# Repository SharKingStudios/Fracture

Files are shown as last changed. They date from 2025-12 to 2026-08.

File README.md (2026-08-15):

# Fracture - The Infinitely Chainable MIDI Keyboard

### A modular, glowing wall of keys with its own brain, synth, and buzzer per board.

---

## Renders  
*Visuals because everyone loves eye candy.*

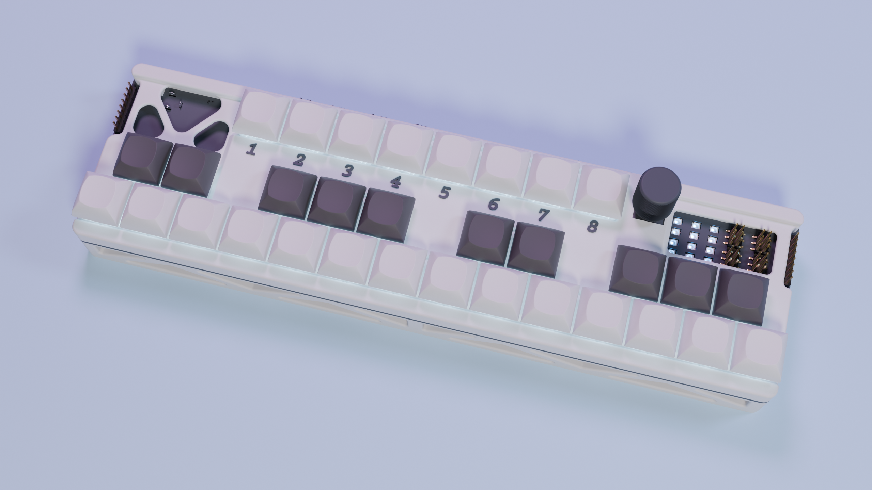
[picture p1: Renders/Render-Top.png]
Front Render

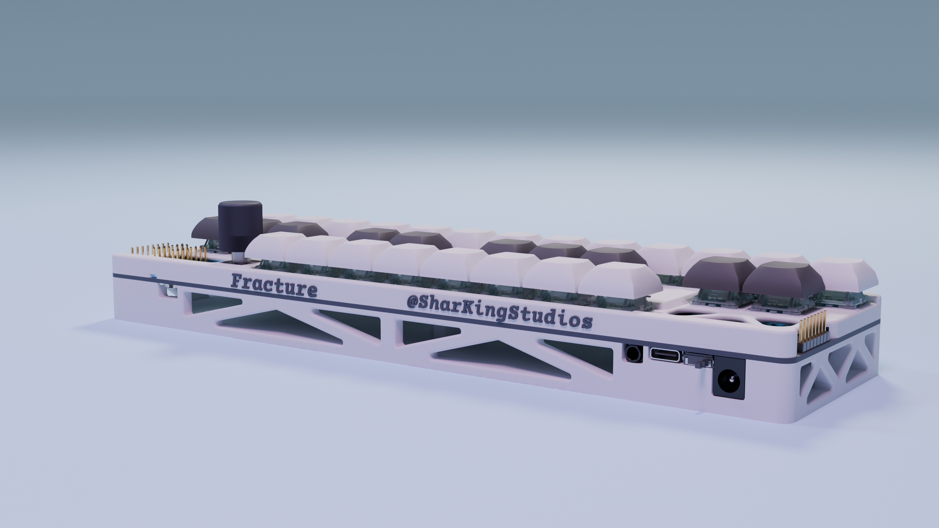
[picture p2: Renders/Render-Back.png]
Angled Render

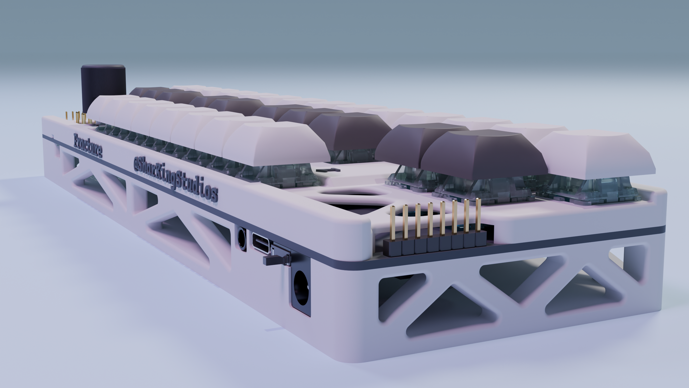
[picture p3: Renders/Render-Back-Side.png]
Angled Render

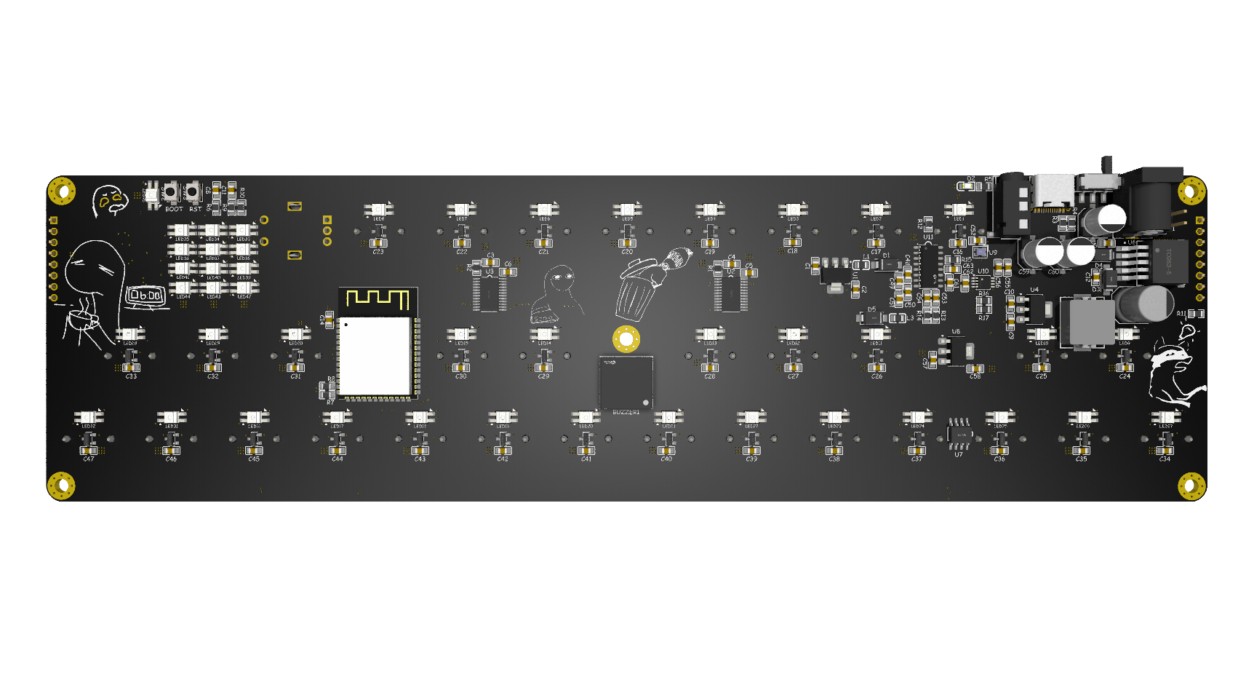
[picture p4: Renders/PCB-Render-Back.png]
Back PCB Render

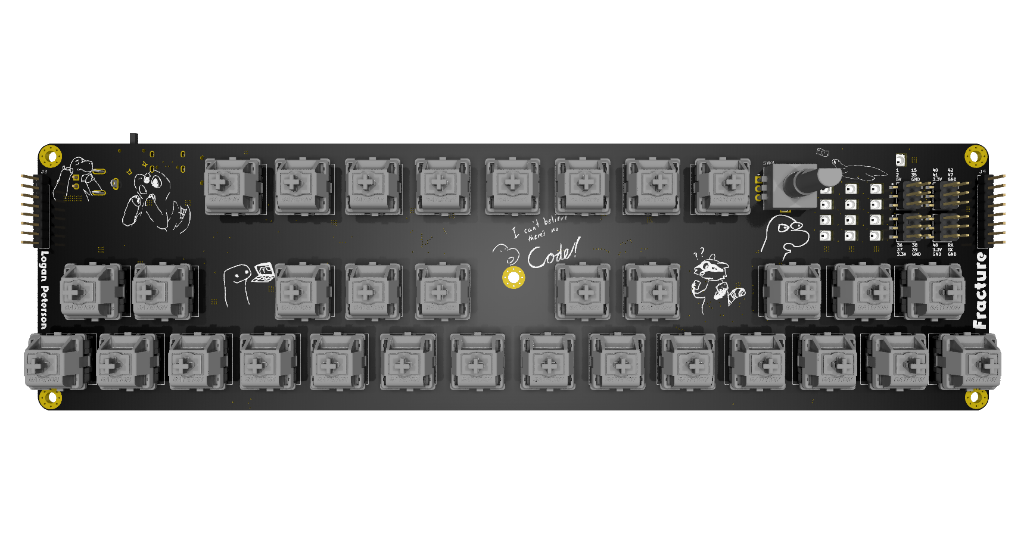
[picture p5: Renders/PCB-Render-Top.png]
Top PCB Render

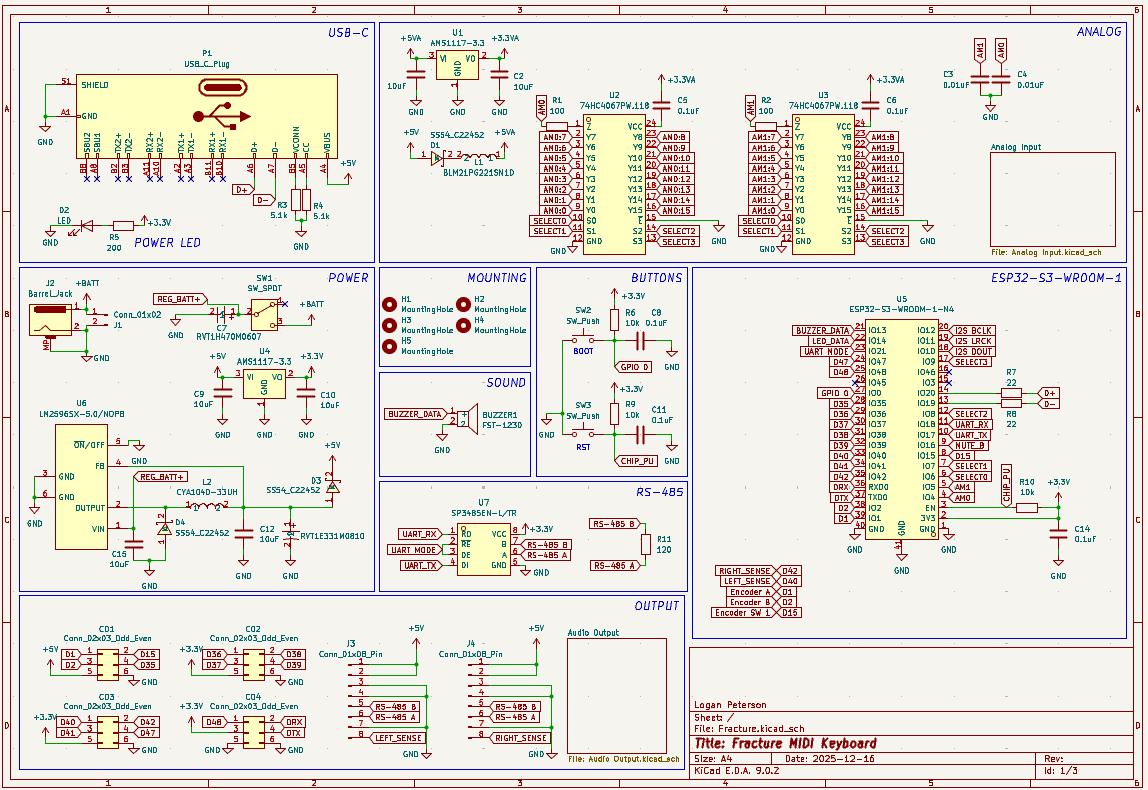
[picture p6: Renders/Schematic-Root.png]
Schematic Overview

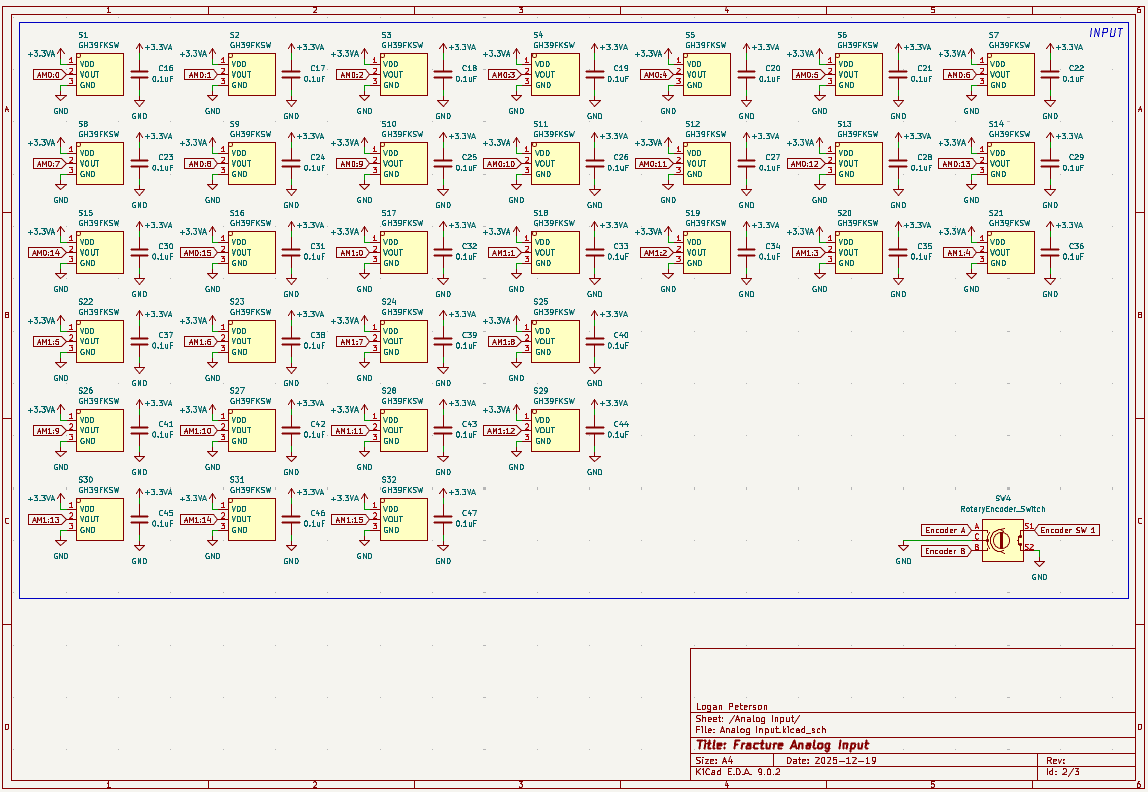
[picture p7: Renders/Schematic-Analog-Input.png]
Schematic Overview

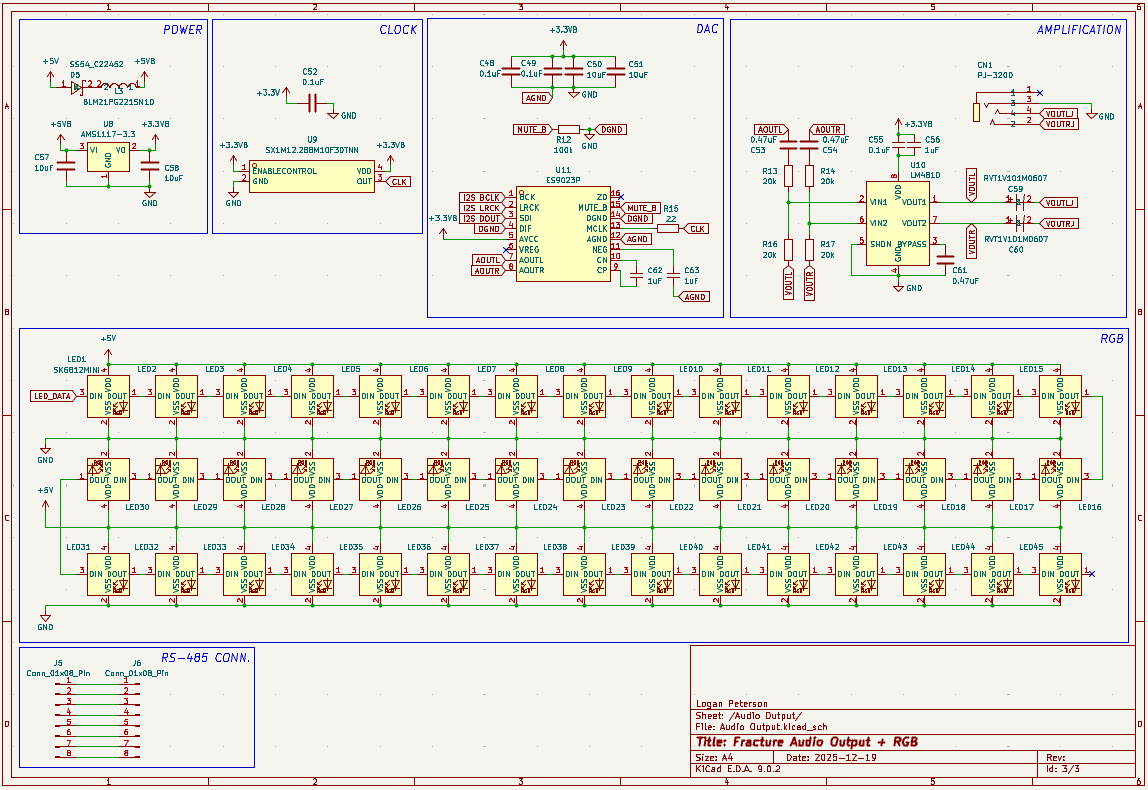
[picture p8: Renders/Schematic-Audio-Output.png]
Schematic Overview

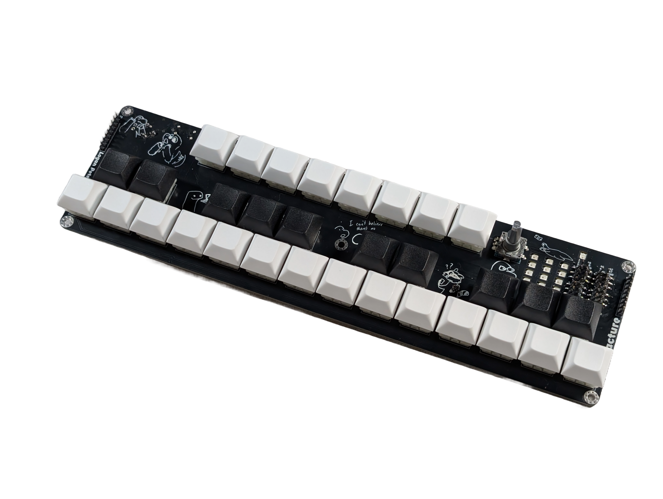
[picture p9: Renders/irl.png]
Irl Picture


---

## What is this?

It's an infinitely expandable MIDI keyboard system built around an ESP32-S3, designed so each board is a fully-featured synth module. When you connect a bunch together, they behave like one giant, continuous instrument.
Each board gives you **2 octaves** of hall-effect keys (24 main keys), plus 8 “function” keys for extra tricks. It also has **onboard I2S audio output**, a buzzer synth per board, and 45 addressable RGB LEDs for underglow + status.
Boards talk to each other over **RS-485 chaining** so note events get shared, and it also does **USB MIDI**, meaning any board plugged into your computer speaks for the whole keyboard.

One board is fun.  
Four boards gives you a full velocity sensing piano.

---

## Features

### Infinitely Chainable Boards

Each board is its own little 2-octave chunk: **24 main keys** and **8 extra keys** for function/mode stuff. The boards discover each other physically using an **RS-485 bus** (SP3485) and **left/right neighbor sense pins**, so you can keep chaining them together.

---

### Hall-Effect Velocity Sensing

No mushy rubber domes here. Keys are read using dual **74HC4067 analog multiplexers**, and velocity is computed using the time between “start of motion” and “fully pressed”.

It’s all done in firmware - no external velocity hardware, just some math and a lot of analog readings.

---

### Onboard Polyphonic Synth (I2S DAC)

Each board is a tiny synth. It uses an **ES9023P I2S DAC** driven at **44.1 kHz, stereo**, and supports up to *8 simultaneous voices*.

You don’t *need* a computer to hear anything, the keyboard can sing on its own.

---

### Polyphonic Buzzer Per Board

Because one audio path wasn’t enough. Each board also has a **timer-driven buzzer synth** that runs at a **20 kHz sample rate**. It’s used for a startup jingle, any feedback sounds, and mild harassment of anyone nearby.

---

### RGB Overlay (Key Underglow + Debug UI)

Each board has **45 WS2812 LEDs** and they’re not just there to look pretty (but they do). Every note triggers a *“splash in the pond”* ripple, and the ripple spreads based on *MIDI note distances*, not physical LED position. Since note events are shared over RS-485, the ripple effect works *across all boards*.

Basically: the keyboard tells you how it feels in RGB.

---

### USB MIDI for the Entire Chain

Any board plugged into USB exposes MIDI for **all** boards. So you can plug in literally any board in the chain, open your DAW / synth, and play the entire keyboard from that one cable.

---

### Rotary Encoder

Because knobs are scientifically proven to make things better.

Long Top Render

---

## BOM

All the silicon, magnetics, and glowsticks live **[here](/BOM.csv)**.

---

### CAD

The CAD is open source **[here](https://cad.onshape.com/documents/bea10ccfe312cfdc51de28f9/w/cdd1b06aedba101817164f81/e/67c5d527eacfd380be4e1fa2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)**.

---

## Why?

Because regular MIDI controllers are boring. Off-the-shelf keyboards don’t re-map themselves and you usually cant chain them together.

Fracture exists to be modular, mildly smart, and just slightly over-engineered.

I honestly thought this would be an easier project, but feature creep got the best of me...

---

## Usage

After you have your board, follow [this guide](/Firmware/Fracture_Keyboard/SONG_MODE.md) for flashing settings and flash [Fracture_Keyboard.ino](/Firmware/Fracture_Keyboard/Fracture_Keyboard.ino) onto your board.

---

## Contribute

Ideas, improvements, and constructive roasting welcome.

- Open an **issue**
- Submit a **PR**
- Or suggest cursed new expansion ideas

---

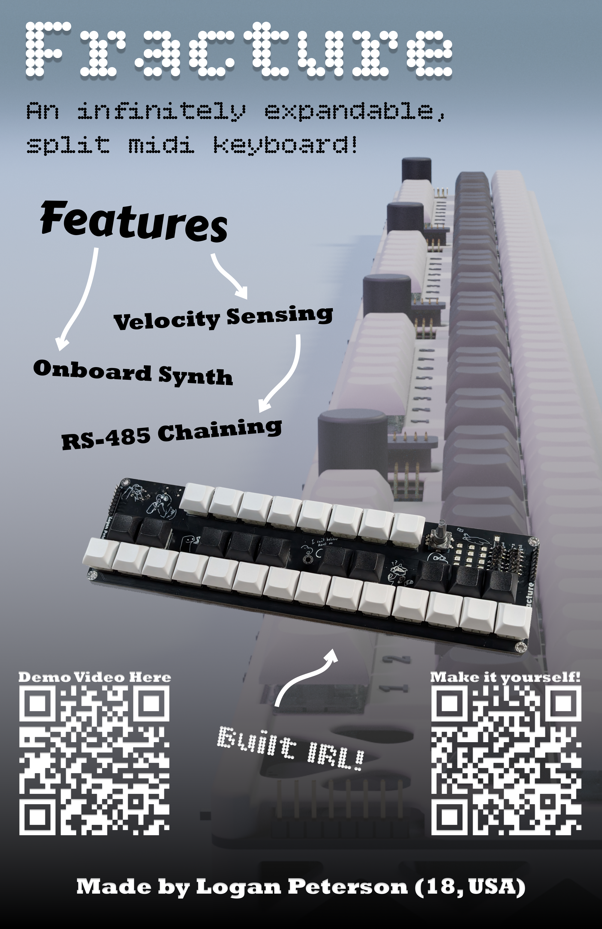
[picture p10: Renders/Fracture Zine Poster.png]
Fracture Poster


## Disclaimer

This project is open-source and powered by *vibes and a sprinkle of C++*.

If you:
- Somehow mess up the RS-485 bus 
- Drive speakers directly off something that shouldn’t  
- Misconfigure power and let the smoke out  

That’s on you.

Be careful, be smart, and enjoy building a keyboard that expands with your musical ability.

Long Side Render

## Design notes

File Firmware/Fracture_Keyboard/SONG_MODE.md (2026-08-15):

# Song Learning Mode

## Arduino settings

The song drive requires a partition scheme containing a partition named `ffat` and TinyUSB/USB-OTG mode.

- Generic ESP32-S3 with 4 MB flash: use `Partition Scheme > No OTA (2MB APP/2MB FATFS)` and `USB Mode > USB-OTG (TinyUSB)`.
- Keep `USB CDC On Boot`, `USB Firmware MSC On Boot`, and `USB DFU On Boot` disabled. Fracture must configure USB itself before `USB.begin()` so normal MIDI and loader MSC do not race each other.
- The stock Arduino Nano ESP32 profile enables USB services before `setup()` and does not expose controls to disable all of them. It is therefore not supported by this composite MIDI/song-loader firmware; use an ESP32-S3 profile that exposes the settings above.
- Do not select a SPIFFS-only partition. When the real `ffat` storage cannot open, loader mode falls back to a small diagnostic USB drive named `SONG LOADER` with a `README.TXT`.

The first boot formats a blank FAT partition. Later mount failures are not auto-formatted, so an unsafe disconnect cannot silently erase stored songs.

## Controls

Normal mode:

- `S6`: enter song select.
- `S7`: refresh/reorder the connected boards.
- Encoder press: toggle the shared buzzer immediately.

Song modes:

- Encoder rotation: move through songs or the available hand choices.
- Encoder press: select/confirm.
- `S1`: escape/back. From the USB loader it safely leaves loader mode after eject/copying is complete.
- `S2` / `S3`: shared octave down/up by one octave. `S4`: reset to the base octave. `S5`: reveal the current title. Audio toggles from normal mode only.
- `S6`: intentionally does nothing while a song mode is active. It cannot delete songs.
- `S7` / `S8`: previous/next browser item or hand choice. If `LOAD SONG` is selected, `S8` enters the loader.

The first browser item is always `LOAD SONG`. Every other entry is collected from the FAT storage on every connected board, so a song stored on one board can be selected from any board.

## Loading files

1. Connect a USB **data** cable directly from the computer to the board on which you want to store the file. The inter-board link does not expose a computer drive.
2. Press `S6` on that board, leave `LOAD SONG` selected, and press the encoder or `S8`. The selected board turns green and the other boards remain orange, so the USB target is unambiguous.
3. The selected board restarts into loader mode and mounts its **actual song library** as the `Fracture Songs` drive. It remains a MIDI device while the drive is present; normal boots expose MIDI only. The restart is required so USB can enumerate the storage interface safely.
4. Use the computer's file explorer to add, rename, or delete Standard MIDI files (`.mid` or `.midi`, format 0 or 1). The current songs are visible immediately; there is no separate staging area.
5. Eject the drive in the operating system. If eject is unavailable, wait for copying to finish and press `S1`.

The loader gives the computer exclusive access to that board's song library. Always eject before pressing `S1` or disconnecting USB; after exit, the firmware restarts, rescans the files, sends a green update wave from the leftmost key to the rightmost key, and rebuilds the distributed song list.

Outside song-menu navigation, encoder rotation changes the shared octave in one-octave steps. In the song browser and hand selector, it moves the menu selection instead.

The loader presents the board's existing FFat song volume directly, using its native wear-leveling geometry. Do not open or change files on both the board and computer at once; loader mode makes the board's local filesystem inactive until it exits.

## Learning behavior

Notes sharing the same MIDI tick are treated as a chord. The guide remains on that chord until every required note has been pressed; wrong notes do not advance it.

- Left hand: green.
- Right hand: red.
- Unknown hand: red.

Hand data is accepted when all note streams have explicit track names such as `Left`, `LH`, `Bass`, `Right`, `RH`, or `Treble`. For an unnamed two-stream piano file, the lower-average stream is inferred as left and the higher-average stream as right. The assignment stays attached to the whole MIDI stream, so either hand may cross the full keyboard. If the assignment is not reliable, the hand selector is skipped and every guide key is red.

Current limits are 16 files per board, 64 files across the chain, and 12,000 note-on events in the loaded song. Browser titles are shortened to 24 characters for the RS-485 packet.

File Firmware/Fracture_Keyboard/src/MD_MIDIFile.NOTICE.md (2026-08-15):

# MD_MIDIFile Notice

`MD_MIDIFile` 2.6.0 by Marco Colli / MajicDesigns is vendored here under LGPL-2.1 from:

https://github.com/MajicDesigns/MD_MIDIFile

Source revision: `ba4717e3c2ffb52de2fee10e7926138a1b9986d4`

Fracture-specific changes are intentionally confined to the vendored parser files:

- Replaced the SdFat file backend with Arduino `fs::FS` / `fs::File` so MIDI files can be read from ESP32 `FFat`.
- Added an absolute tick field to MIDI and metadata callbacks for chord grouping.
- Bounded metadata string termination.
- Kept full-path selection in the application instead of changing an SD-card working directory.

The complete upstream license is in `MD_MIDIFile.LICENSE`.

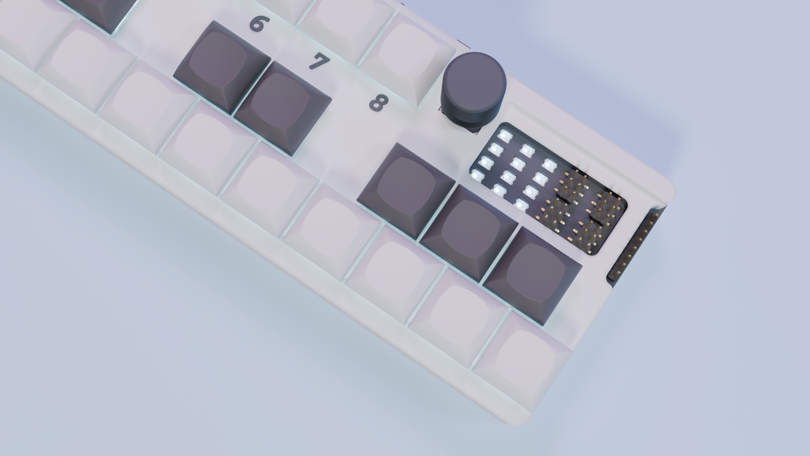
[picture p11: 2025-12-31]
Renders/Render-Top-Angled.png

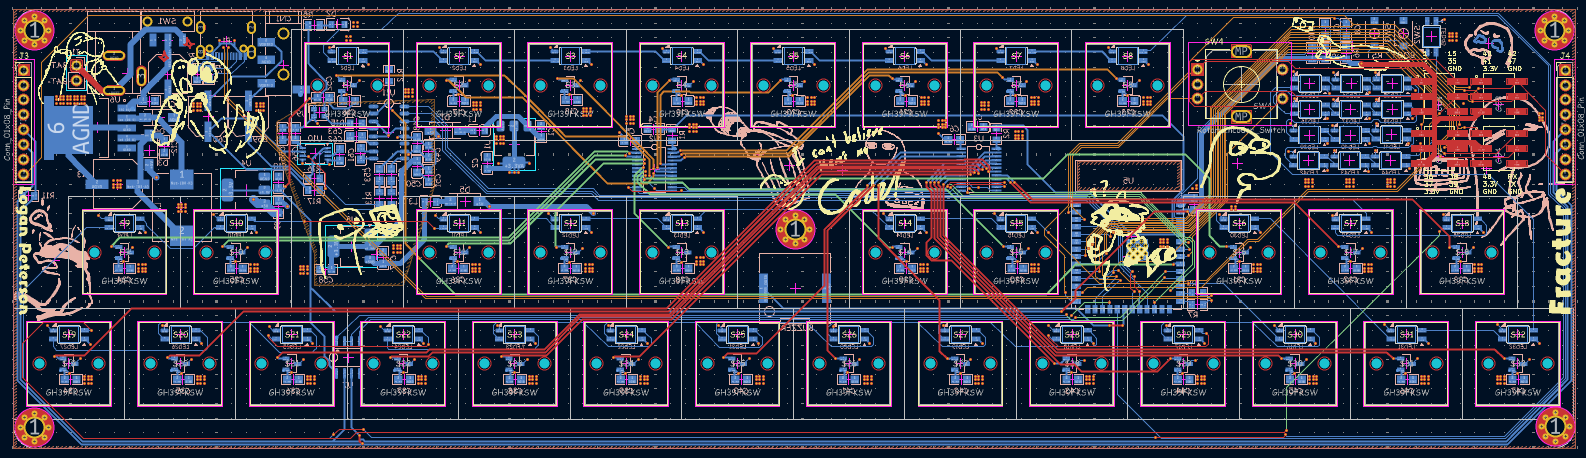
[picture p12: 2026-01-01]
Renders/PCB-Routing.png

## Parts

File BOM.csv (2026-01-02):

Value | Qty | Price Ea. | Price total (MOQ) | Item link
CL21A106KAYNNNE (10uF 25V X5R 0805) | 40 | 0.0100 | 0.43 | https://www.lcsc.com/product-detail/C15850.html
CL21B103KBCNNNC (0.01uF 50V X7R 0805) | 8 | 0.0095 | 0.48 | https://www.lcsc.com/product-detail/C84715.html
CL21B104KBCNNNC (0.1uF 50V X7R 0805) | 164 | 0.0063 | 1.26 | https://www.lcsc.com/product-detail/C1711.html
CL21B474KAFNNNE (0.47uF 25V X7R 0805) | 12 | 0.0114 | 0.57 | https://www.lcsc.com/product-detail/C15972.html
CL21B105KBFNNNE (1uF 50V X7R 0805) | 12 | 0.0092 | 0.18 | https://www.lcsc.com/product-detail/C28323.html
0805W8F1000T5E (100Ω ±1% 0805) | 8 | 0.0019 | 0.19 | https://www.lcsc.com/product-detail/C17408.html
0805W8F5101T5E (5.1kΩ ±1% 0805) | 8 | 0.0019 | 0.19 | https://www.lcsc.com/product-detail/C27834.html
0805W8F2000T5E (200Ω ±1% 0805) | 4 | 0.0019 | 0.19 | https://www.lcsc.com/product-detail/C17540.html
0805W8F1002T5E (10kΩ ±1% 0805) | 12 | 0.0021 | 0.21 | https://www.lcsc.com/product-detail/C17414.html
0805W8F220JT5E (22Ω ±1% 0805) | 12 | 0.0020 | 0.20 | https://www.lcsc.com/product-detail/C17561.html
0805W8F1200T5E (120Ω ±1% 0805) | 4 | 0.0020 | 0.20 | https://www.lcsc.com/product-detail/Chip-Resistor-Surface-Mount_UNI-ROYAL-Uniroyal-Elec_C17437.html
0805W8F1003T5E (100kΩ ±1% 0805) | 4 | 0.0019 | 0.19 | https://www.lcsc.com/product-detail/C149504.html
0805W8F2002T5E (20kΩ ±1% 0805) | 16 | 0.0020 | 0.20 | https://www.lcsc.com/product-detail/C4328.html
RVT1H470M0607 (47uF 50V electrolytic) | 4 | 0.0310 | 0.62 | https://www.lcsc.com/product-detail/C72523.html
RVT1E331M0810 (330uF electrolytic) | 4 | 0.0567 | 0.57 | https://www.lcsc.com/product-detail/C335985.html
RVT1V101M0607 (100uF 35V electrolytic) | 8 | 0.03 | 0.60 | https://www.lcsc.com/product-detail/C72478.html
SS54 (Schottky diode) | 16 | 0.0434 | 0.87 | https://www.lcsc.com/product-detail/C22452.html
LED 0805 (purple) | 4 | 0.131 | 0.66 | https://www.lcsc.com/product-detail/C7371915.html
BLM21PG221SN1D (Ferrite bead 0805) | 8 | 0.0166 | 0.83 | https://www.lcsc.com/product-detail/C85840.html
CYA1040-33UH (33uH inductor) | 4 | 0.3363 | 1.68 | https://www.lcsc.com/product-detail/C6364680.html
MST-12D18G4 (SPDT slide switch) | 4 | 0.0768 | 0.38 | https://www.lcsc.com/product-detail/C49023767.html
TS-1088-AR02016 (tactile switch 4x3mm) | 8 | 0.0445 | 0.45 | https://www.lcsc.com/product-detail/C720477.html
Rotary Encoder (Alps EC11E w/ switch) | 4 | 1.83 | 7.32 | https://www.lcsc.com/product-detail/C470742.html
USB-C receptacle (USB-TYPE-C-018 / C2927038) | 4 | 0.051 | 0.51 | https://www.lcsc.com/product-detail/C2927038.html
DC Barrel Jack DC-005-A200 | 4 | 0.1169 | 0.58 | https://www.lcsc.com/product-detail/C720557.html
PJ-320D (3.5mm audio jack) | 4 | 0.0969 | 0.48 | https://www.lcsc.com/product-detail/C521460.html
PinHeader 1x40 2.54mm vertical | 2 | 0.1177 | 0.59 | https://www.lcsc.com/product-detail/C2337.html
PinSocket 1x40 2.54mm vertical | 2 | 0.2112 | 1.06 | https://www.lcsc.com/product-detail/C47940.html
2x3 SMD header 2.54mm (Conn_02x03) | 3 | 0.2521 | 1.26 | https://www.lcsc.com/product-detail/C5378173.html
AMS1117-3.3 (SOT-223) | 12 | 0.16 | 2.51 | https://www.lcsc.com/product-detail/C6186.html
74HC4067PW 118 (TSSOP-24) | 8 | 0.46 | 4.61 | https://www.lcsc.com/product-detail/C179326.html
ESP32-S3-WROOM-1-N4 | 4 | 4.35 | 17.40 | https://www.lcsc.com/product-detail/C2913197.html
LM2596SX-5.0/NOPB (TO-263-5) | 4 | 0.86 | 3.44 | https://www.lcsc.com/product-detail/C10002.html
SP3485EN-L/TR (SOIC-8) | 4 | 0.20 | 0.80 | https://www.lcsc.com/product-detail/C8963.html
12.288MHz Oscillator (2.0x1.6mm) | 4 | 0.62 | 2.5 | https://www.lcsc.com/product-detail/C2901609.html
LM4810 (TSSOP-8) | 4 | 0.87 | 3.48 | https://www.lcsc.com/product-detail/C2864060.html
ES9023P (SOP-16) | 4 | 1.505 | 6.02 | https://www.lcsc.com/product-detail/C2760388.html
FST-1230 (Buzzer) | 4 | 0.4646 | 1.86 | https://lcsc.com/product-detail/Buzzers_FST-FST-1230_C391037.html
GH39FKSW (SOT-23-3 sensor) | 128 | 0.108 | 14.62 | https://www.lcsc.com/product-detail/C266230.html
SK6812MINI E | 180 | 0.06 | 11.48 | https://www.lcsc.com/product-detail/C5149201.html
LCSC Merchandise Subtotal |  |  |  | 106.30
LCSC Shipping Estimate |  |  |  | 14.73
LCSC Taxes Buffer |  |  |  | 8.00
LCSC Total |  |  |  | 128.03
Hall Effect Keyswitches (pack of 35) | 4 | 12.99 | 52.00 | https://www.amazon.com/dp/B0DWXNQ65W
Black 1U Keycaps (pack of 24) | 2 | 8.99 | 18.00 | https://www.amazon.com/Mechkeeb-Profile-Switches-Keyboard-Replacement/dp/B0BWDQ3NKK
White 1U Keycaps (pack of 24) | 4 | 8.99 | 36.00 | https://www.amazon.com/Mechkeeb-Profile-Switches-Keyboard-Replacement/dp/B0BWDTBF1L
External Merchandise Subtotal |  |  |  | 106.00
External Shipping Estimate |  |  |  | 0.00
External Taxes Buffer |  |  |  | 8.00
External Total |  |  |  | 114.00
JLCPCB Main Board Fabrication | 5 |  |  | 42.20
JLCPCB Stencil | 1 |  |  | 7.00
JLCPCB Shipping Estimate |  |  |  | 30.00
JLCPCB Connectors Fabrication |  |  |  | 2.00
JLCPCB Connectors Shipping Estimate |  |  |  | 8.00
JLCPCB Taxes Buffer |  |  |  | 3.00
JLCPCB Total |  |  |  | 92.20
Grand Total |  |  |  | 334.23

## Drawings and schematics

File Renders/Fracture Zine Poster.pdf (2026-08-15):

# Fracture

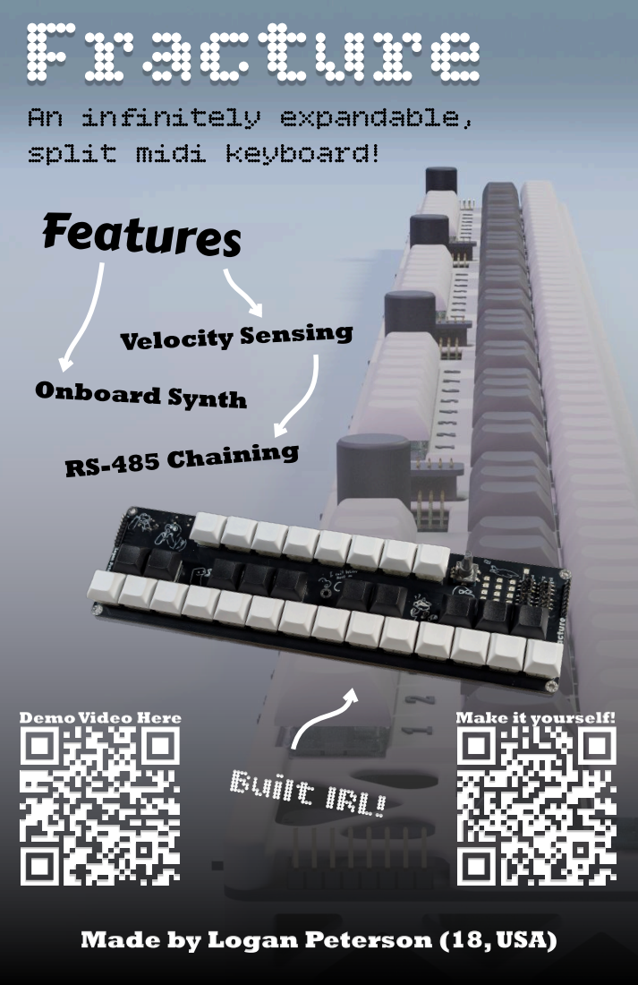
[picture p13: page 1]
Features; Velocity Sensing; Onboard Synth; RS-485 Chaining; Demo Video Here; Make it yourself!; Built IRL!

An infinitely expandable,
split midi keyboard!

Made by Logan Peterson (18, USA)

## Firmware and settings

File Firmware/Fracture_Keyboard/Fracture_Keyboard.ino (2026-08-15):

/*
  Infinite MIDI Keyboard – ESP32-S3 (Polished Version)

  Features:
  - 2 octaves per board (24 keys) + 8 extra keys (32 total)
  - 2x 74HC4067 (16+16 channels)
  - Hall-effect velocity sensing (time delta based)
  - WS2812 LEDs (45 total):
      * 1–32 under keys (0–31 index)
      * 33–44 status (32–43 index)
      * 45th LED (index 44) top-left:
          - Yellow while remapping
          - Light green pulse when network healthy
  - LED base color: light blue under all keys
  - Keypress ripple: white “splash in the pond” based on MIDI note distances,
    propagating across all boards.
  - Buzzer:
      * Startup jingle
      * Polyphonic (up to 12 notes) for this board’s keys only
  - I2S DAC (ES9023P) sine-wave poly synth
  - RS-485 (SP3485) bus:
      * Physical left/right chain mapping via IO1/IO2
      * Each board gets an index 0..N-1, left→right
      * NOTE events shared across boards
      * Board 0 pings others, auto-remap on missing nodes
      * Auto-remap on new ANNOUNCE IDs
  - USB MIDI:
      * Uses ESP32 USBMIDI / TinyUSB when USB-OTG mode is selected
      * Any board plugged into USB outputs MIDI for the whole keyboard

  Neighbor wiring assumption:
    - IO40 = LEFT neighbor signal (INPUT_PULLUP).
    - IO42 = RIGHT neighbor signal (OUTPUT).
    - Each board’s IO42 connects to the next board’s IO40 on its right.
*/

#include <Arduino.h>
#if defined(ARDUINO_ARCH_ESP32) && __has_include(<esp_arduino_version.h>)
#include <esp_arduino_version.h>
#endif
#if defined(ARDUINO_ARCH_ESP32) && __has_include(<soc/soc_caps.h>)
#include <soc/soc_caps.h>
#endif
#include <Adafruit_NeoPixel.h>
#include <driver/i2s.h>
#include <HardwareSerial.h>
#include <math.h>
#include "driver/gpio.h"
#include "FractureSongSystem.h"
#if defined(ARDUINO_ARCH_ESP32) && defined(SOC_USB_OTG_SUPPORTED) && SOC_USB_OTG_SUPPORTED && defined(ARDUINO_USB_MODE) && !ARDUINO_USB_MODE
#include "USB.h"
#include <USBMIDI.h>
#if defined(CONFIG_TINYUSB_MIDI_ENABLED) && CONFIG_TINYUSB_MIDI_ENABLED
#define FRACTURE_USB_DEVICE_ENABLED 1
#define FRACTURE_USB_MIDI_ENABLED 1
#else
#error "Fracture requires TinyUSB MIDI support in the selected ESP32 board configuration."
#endif
#else
#define FRACTURE_USB_DEVICE_ENABLED 0
#define FRACTURE_USB_MIDI_ENABLED 0
#endif

#if defined(ARDUINO_USB_MODE) && ARDUINO_USB_MODE
#error "Set Tools > USB Mode to USB-OTG (TinyUSB) for Fracture MIDI."
#endif
#if defined(ARDUINO_USB_CDC_ON_BOOT) && ARDUINO_USB_CDC_ON_BOOT
#error "Disable USB CDC On Boot; it starts TinyUSB before Fracture can select MIDI and song-loader MSC."
#endif
#if defined(ARDUINO_USB_MSC_ON_BOOT) && ARDUINO_USB_MSC_ON_BOOT
#error "Disable USB Firmware MSC On Boot; Fracture supplies its own song-loader MSC."
#endif
#if defined(ARDUINO_USB_DFU_ON_BOOT) && ARDUINO_USB_DFU_ON_BOOT
#error "Disable USB DFU On Boot; Fracture must be the first code to start TinyUSB."
#endif

#ifndef FRACTURE_ENABLE_I2S_AUDIO
#define FRACTURE_ENABLE_I2S_AUDIO 0
#endif

#ifndef FRACTURE_ENABLE_EXTRA_KEYS
#define FRACTURE_ENABLE_EXTRA_KEYS 1
#endif

#ifndef FRACTURE_ENABLE_BUZZER_SYNTH
#define FRACTURE_ENABLE_BUZZER_SYNTH 1
#endif
// ========================= PIN DEFINITIONS =========================

// Physical neighbor chain pins
#define PIN_NEIGHBOR_LEFT    40   // IO40: left neighbor signal (input)
#define PIN_NEIGHBOR_RIGHT   42   // IO42: right neighbor signal (output)

// Encoder
#define PIN_ENC_A            1
#define PIN_ENC_B            2
#define PIN_ENC_SW           15

// LEDs
#define PIN_LED_DATA         14   // WS2812, 45 LEDs

// Buzzer (now driven by timer-based polyphonic synth)
#define PIN_BUZZER           13

// RS-485 (SP3485)
#define PIN_RS485_MODE       21   // DE/RE
#define PIN_RS485_TX         17
#define PIN_RS485_RX         18

// Multiplexer selects (74HC4067)
#define PIN_MUX_S0           6
#define PIN_MUX_S1           7
#define PIN_MUX_S2           8
#define PIN_MUX_S3           9

// Multiplexer analog inputs
#define PIN_AM0              4   // Extra keys + main keys
#define PIN_AM1              5   // Main keys

// I2S DAC (ES9023P)
#define PIN_I2S_BCLK         12
#define PIN_I2S_LRCK         11
#define PIN_I2S_DOUT         10
#define PIN_DAC_MUTE_B       16

// ========================= CONSTANTS ===============================

// Keys
const uint8_t NUM_MAIN_KEYS   = 24;   // musical keys
const uint8_t NUM_EXTRA_KEYS  = 8;    // function keys
const uint8_t TOTAL_KEYS      = 32;   // 24 + 8

// LEDs
const uint16_t NUM_LEDS       = 45;   // 32 keys, 12 status, 1 top-left

// MIDI note layout
const uint8_t GLOBAL_BASE_NOTE = 48;  // C3 as first board's first note
const uint8_t BOARD_NOTE_SPAN  = 24;  // 2 octaves per board

// RS-485
HardwareSerial RS485(1);
const uint32_t RS485_BAUD       = 250000;
const uint8_t  RS485_MAX_NODES  = 16;

// RS-485 message types
const uint8_t  RS485_ANNOUNCE_MSG      = 0x01; // nodeId + boardIndex
const uint8_t  RS485_NOTE_MSG          = 0x02; // nodeId + note + vel + on/off
const uint8_t  RS485_PING_MSG          = 0x03; // ping sequence
const uint8_t  RS485_PING_REPLY_MSG    = 0x04; // nodeId + seq
const uint8_t  RS485_REMAP_REQUEST_MSG = 0x05; // trigger re-discovery
const uint8_t  RS485_CONTROL_MSG       = 0x06; // nodeId + command + value
const uint8_t  RS485_REMAP_FINAL_MSG   = 0x07; // generation + board count

const uint8_t  CONTROL_BUZZER_ENABLED  = 0x01;
const uint8_t  CONTROL_OCTAVE_OFFSET   = 0x02;
const uint8_t  CONTROL_AUDIO_ENABLED   = 0x03;
const uint8_t  CONTROL_SIGNED_BIAS     = 64;

// Discovery / mapping
const uint32_t DISCOVERY_MAX_MS        = 1000; // total time budget for chain setup
const uint32_t REMAP_VISUAL_MS         = 900;  // visible refresh flash after discovery
const uint32_t DISCOVERY_NEIGHBOR_SETTLE_MS = 35; // hold neighbor detect state long enough to synchronize
const uint32_t DISCOVERY_RETRY_MS      = 80;   // repeat the left-to-right discovery token
const uint32_t DISCOVERY_PARENT_ANNOUNCE_MS = 30; // announce-to-pulse pairing window
const uint32_t REMAP_START_DELAY_MS   = 140;  // let every board enter refresh before discovery
const uint8_t  REMAP_REQUEST_REPEATS  = 3;

// Velocity sensing
const uint16_t VELOCITY_ON_DELTA     = 80;    // change from baseline to detect press start
const uint16_t VELOCITY_FULL_DELTA   = 120;   // lower threshold keeps weaker Hall sensors playable
const uint16_t VELOCITY_MIN_DT_US    = 1000;  // very fast strike
const uint32_t VELOCITY_MAX_DT_US    = 60000; // very slow strike
const uint8_t  KEY_ADC_AVERAGE_SAMPLES = 4;
const uint8_t  KEY_PRESS_DEBOUNCE_SCANS = 3;
const uint8_t  KEY_RELEASE_DEBOUNCE_SCANS = 2;
const uint8_t  KEY_NOTE_ON_MAX_SCANS = 6;
const uint16_t KEY_MUX_SETTLE_US = 80;
const uint16_t KEY_ADC_SETTLE_US = 20;
const uint32_t AUX_HOLD_US = 220000UL;
const uint32_t SETTINGS_AFTER_KEYS_COOLDOWN_MS = 1200;

// Audio synth (I2S)
const i2s_port_t I2S_PORT = I2S_NUM_0;
const uint32_t AUDIO_SAMPLE_RATE = 44100;
const uint8_t MAX_VOICES = 8;
const float MASTER_VOLUME = 0.4f;

// Buzzer synth
const uint8_t  BUZZER_PWM_RESOLUTION = 10;
const uint16_t BUZZER_PWM_DUTY = 256;               // 25% duty is less harsh than 50%
const int8_t   BUZZER_NOTE_TRANSPOSE = 12;          // small buzzers speak cleaner one octave up
const uint8_t  BUZZER_PWM_CHANNEL = 0;               // Arduino-ESP32 2.x LEDC channel
const int8_t   OCTAVE_SHIFT_MIN = -4;                // C3 down to MIDI note 0
const int8_t   OCTAVE_SHIFT_MAX = 4;                 // one-board upper limit

// Encoder
const int8_t ENCODER_EDGES_PER_DETENT = 2;           // EC11E: 9 pulses / 18 detents

#if defined(ESP_ARDUINO_VERSION_MAJOR) && ESP_ARDUINO_VERSION_MAJOR >= 3
#define FRACTURE_LEDC_PIN_API 1
#else
#define FRACTURE_LEDC_PIN_API 0
#endif

// Ping / remap
const uint32_t PING_INTERVAL_MS = 1000;
const uint32_t PING_TIMEOUT_MS  = 200;

// Ripple (LED splash)
const float RIPPLE_SPEED = 0.018f; // wave radius in semitones/ms
const uint8_t MAX_RIPPLES = 8;
const uint8_t STATUS_ROWS = 4;
const uint8_t STATUS_COLS = 3;
const uint16_t STATUS_FIRST_LED = 32;
const uint32_t STATUS_FADE_MS = 147;
const uint8_t STATUS_DISPLAY_BRIGHTNESS_SCALE = 128;

// ========================= TYPES & STRUCTS =========================

struct NodeInfo {
  uint32_t nodeId;
  uint8_t  boardIndex; // 0..N-1
};

struct NodeList {
  uint8_t  count = 0;
  NodeInfo nodes[RS485_MAX_NODES];
};

struct KeyDef {
  uint8_t muxIndex;   // 0 = AM0, 1 = AM1
  uint8_t muxChannel; // 0–15
  bool    isExtra;    // true for extra keys
};

struct KeyState {
  uint16_t raw = 0;
  uint16_t baseline = 0;
  bool     pressed = false;
  bool     velocityComputed = false;
  bool     extraHandled = false;
  bool     extraSuppressed = false;
  uint8_t  aboveCount = 0;
  uint8_t  belowCount = 0;
  uint32_t pressStartUs = 0;
  uint8_t  velocity = 0;
  uint8_t  activeNote = 0;
};

struct Voice {
  bool active = false;
  uint8_t note = 0;
  float phase = 0.0f;
  float phaseInc = 0.0f;
  float amplitude = 0.0f;
};

struct Ripple {
  bool active = false;
  float centerNote = 0.0f;   // MIDI note
  float radius = 0.0f;       // in semitones
  float maxRadius = 24.0f;
  uint32_t startMs = 0;
  uint8_t baseVelocity = 80;
};

struct RxState {
  uint8_t state = 0;
  uint8_t len = 0;
  uint8_t type = 0;
  uint8_t buf[32];
  uint8_t pos = 0;
  uint8_t checksum = 0;
};


// ========================= FORWARD DECLARATIONS ====================

void onLocalNoteOn(uint8_t note, uint8_t velocity);
void onLocalNoteOff(uint8_t note);
void onRemoteNoteOn(uint8_t note, uint8_t velocity, uint8_t sourceBoard);
void onRemoteNoteOff(uint8_t note);
void handleExtraKeyPressed(uint8_t extraIndex);
void rs485SendPacket(uint8_t type, const uint8_t *payload, uint8_t len);
void startDiscovery(bool fromRemap);
void renderLeds();
void buzzerApplySelectedNote();
void buzzerStopAllInternal();
void setSharedBuzzerEnabled(bool enabled, bool broadcast);
void setSharedOctave(int8_t octave, bool broadcast);
void broadcastSharedState();
uint8_t midiNoteToBoardOffset(uint8_t note);

// ========================= GLOBALS =================================

Adafruit_NeoPixel leds(NUM_LEDS, PIN_LED_DATA, NEO_GRB + NEO_KHZ800);

// Register MIDI before setup so TinyUSB always sees it before USB.begin().
#if FRACTURE_USB_MIDI_ENABLED
USBMIDI usbMidi("Fracture Keyboard");
#endif

// Key definitions
KeyDef keyDefs[TOTAL_KEYS];
KeyState keyStates[TOTAL_KEYS];

// Musical mapping: main key index -> semitone offset from boardBaseNote
// For now: black keys first (2 octaves, left→right), then white keys.
// You can remap this later to match your physical layout.
const uint8_t keyToNote[NUM_MAIN_KEYS] = {
  // Black keys (2 octaves)
  1, 3, 6, 8, 10,    // C#1, D#1, F#1, G#1, A#1
  13, 15, 18, 20, 22,// C#2, D#2, F#2, G#2, A#2
  // White keys (2 octaves)
  0, 2, 4, 5, 7, 9, 11,   // C1 D1 E1 F1 G1 A1 B1
  12, 14, 16, 17, 19, 21, 23 // C2 D2 E2 F2 G2 A2 B2
};

// Node discovery
uint32_t myNodeId;
NodeList nodeList;
uint8_t myBoardIndex = 0;
uint8_t totalBoards = 1;
bool discoveryDone = false;
bool remapScheduled = false;
uint32_t remapStartAtMs = 0;
uint16_t currentRemapToken = 0;
uint16_t lastCompletedRemapToken = 0xFFFF;
uint16_t localRemapCounter = 0;
uint8_t lastDiscoveryAnnounceIndex = 0xFF;
uint32_t lastDiscoveryAnnounceMs = 0;

// Network state
bool isRemapping     = false;
bool networkHealthy  = false;
uint32_t lastMainKeyActivityMs = 0;
uint32_t networkRefreshEffectUntilMs = 0;
char statusGlyphCurrent = 0;
char statusGlyphPrevious = 0;
uint32_t statusGlyphTransitionMs = 0;
uint32_t statusGlyphColor = 0;
uint32_t statusGlyphPreviousColor = 0;

// Note mapping
int16_t boardBaseNote = GLOBAL_BASE_NOTE;
int8_t octaveOffset = 0; // shared semitone mapping in one-octave steps

// Synth (I2S)
Voice voices[MAX_VOICES];

// Encoder
volatile int16_t encoderPendingEdges = 0;
int16_t encoderEdgeAccumulator = 0;
uint8_t encoderLastState = 0;
uint8_t encoderLastRoute = 0;

// Modes
bool buzzerEnabled = false;
bool audioEnabled  = FRACTURE_ENABLE_I2S_AUDIO;
bool audioReady    = false;

// Neighbor info
bool hasLeftNeighbor = false;

// RS-485 RX state
RxState rx;

// Ripples + key LED base velocities
Ripple ripples[MAX_RIPPLES];
uint8_t keyBaseVelocity[TOTAL_KEYS]; // 0..127
uint32_t keyBaseStartMs[TOTAL_KEYS];

// Ping
uint8_t pingSequence = 0;
bool awaitingPingReplies = false;
uint32_t pingStartMs = 0;
uint32_t lastPingMs = 0;
bool pingReceived[RS485_MAX_NODES];

// Buzzer synth
bool buzzerPwmReady = false;
uint8_t buzzerNoteCount[128];
uint32_t buzzerNoteOrder[128];
uint8_t buzzerNoteSourceBoard[128];
uint32_t buzzerOrderCounter = 0;
portMUX_TYPE buzzerMux = portMUX_INITIALIZER_UNLOCKED;

// ========================= UTILITY HELPERS =========================

void bootLog(const char *message) {
  Serial.println(message);
  Serial.flush();
}

float midiNoteToFreq(uint8_t note) {
  return 440.0f * powf(2.0f, ((float)note - 69.0f) / 12.0f);
}

int8_t minSharedOctave() {
  return OCTAVE_SHIFT_MIN;
}

int8_t maxSharedOctave() {
  int8_t span = totalBoards == 0 ? 1 : (int8_t)totalBoards;
  int8_t maxOctave = OCTAVE_SHIFT_MAX - 2 * (span - 1);
  return maxOctave < OCTAVE_SHIFT_MIN ? OCTAVE_SHIFT_MIN : maxOctave;
}

int8_t clampOctave(int8_t octave) {
  int8_t minimum = minSharedOctave();
  int8_t maximum = maxSharedOctave();
  if (octave < minimum) return minimum;
  if (octave > maximum) return maximum;
  return octave;
}

void updateBoardBaseNote() {
  uint8_t index = (myBoardIndex == 0xFF) ? 0 : myBoardIndex;
  boardBaseNote = (int16_t)GLOBAL_BASE_NOTE +
                  (int16_t)octaveOffset * 12 + (int16_t)index * BOARD_NOTE_SPAN;
}

bool applyOctaveLocal(int8_t octave) {
  int8_t clamped = clampOctave(octave);
  bool changed = clamped != octaveOffset;
  octaveOffset = clamped;
  updateBoardBaseNote();
  return changed;
}

uint8_t localNoteForMainKey(uint8_t keyIndex) {
  int16_t note = boardBaseNote + keyToNote[keyIndex];
  if (note < 0) return 0;
  if (note > 127) return 127;
  return (uint8_t)note;
}

void triggerNetworkRefreshEffect() {
  networkRefreshEffectUntilMs = millis() + REMAP_VISUAL_MS;
}

void finishNetworkRefreshVisual() {
  networkRefreshEffectUntilMs = 0;
  statusGlyphCurrent = 0;
  statusGlyphPrevious = 0;
  statusGlyphTransitionMs = 0;
}

void scheduleNetworkRemap(uint16_t token) {
  if (discoveryDone && token == lastCompletedRemapToken) return;
  if (token == currentRemapToken && (remapScheduled || isRemapping)) return;
  currentRemapToken = token;
  remapScheduled = true;
  remapStartAtMs = millis() + REMAP_START_DELAY_MS;
  isRemapping = true;
  networkHealthy = false;
  triggerNetworkRefreshEffect();
}

void requestNetworkRemap() {
  uint16_t token = (uint16_t)(++localRemapCounter ^ (uint16_t)millis() ^
                              (uint16_t)(myNodeId >> 16));
  if (token == lastCompletedRemapToken) ++token;
  scheduleNetworkRemap(token);

  uint8_t payload[6];
  payload[0] = myNodeId & 0xFF;
  payload[1] = (myNodeId >> 8) & 0xFF;
  payload[2] = (myNodeId >> 16) & 0xFF;
  payload[3] = (myNodeId >> 24) & 0xFF;
  payload[4] = token & 0xFF;
  payload[5] = (token >> 8) & 0xFF;
  for (uint8_t attempt = 0; attempt < REMAP_REQUEST_REPEATS; ++attempt) {
    rs485SendPacket(RS485_REMAP_REQUEST_MSG, payload, sizeof(payload));
    if (attempt + 1 < REMAP_REQUEST_REPEATS) delay(4);
  }
}

bool buzzerPwmAttach(uint8_t pin, uint32_t freq, uint8_t resolution) {
#if FRACTURE_LEDC_PIN_API
  return ledcAttach(pin, freq, resolution);
#else
  if (ledcSetup(BUZZER_PWM_CHANNEL, freq, resolution) <= 0) return false;
  ledcAttachPin(pin, BUZZER_PWM_CHANNEL);
  return true;
#endif
}

void buzzerPwmWrite(uint32_t duty) {
#if FRACTURE_LEDC_PIN_API
  ledcWrite(PIN_BUZZER, duty);
#else
  ledcWrite(BUZZER_PWM_CHANNEL, duty);
#endif
}

void buzzerPwmChangeFrequency(uint32_t freq) {
#if FRACTURE_LEDC_PIN_API
  ledcChangeFrequency(PIN_BUZZER, freq, BUZZER_PWM_RESOLUTION);
#else
  ledcChangeFrequency(BUZZER_PWM_CHANNEL, freq, BUZZER_PWM_RESOLUTION);
#endif
}

// Given a note, find local main key index that maps to it, or 0xFF if not on this board
uint8_t keyIndexFromNote(uint8_t note) {
  int16_t offset = (int16_t)note - boardBaseNote;
  if (offset < 0 || offset >= BOARD_NOTE_SPAN) return 0xFF;
  for (uint8_t i = 0; i < NUM_MAIN_KEYS; i++) {
    if (keyToNote[i] == offset) return i;
  }
  return 0xFF;
}

// ========================= MUX & KEYS ==============================

void setMuxChannel(uint8_t channel) {
  digitalWrite(PIN_MUX_S0, channel & 0x01);
  digitalWrite(PIN_MUX_S1, (channel >> 1) & 0x01);
  digitalWrite(PIN_MUX_S2, (channel >> 2) & 0x01);
  digitalWrite(PIN_MUX_S3, (channel >> 3) & 0x01);
  delayMicroseconds(KEY_MUX_SETTLE_US);
}

uint16_t readKeyRaw(const KeyDef &def) {
  setMuxChannel(def.muxChannel);
  int pin = (def.muxIndex == 0) ? PIN_AM0 : PIN_AM1;
  analogRead(pin);
  analogRead(pin);
  delayMicroseconds(KEY_ADC_SETTLE_US);

  uint32_t sum = 0;
  for (uint8_t i = 0; i < KEY_ADC_AVERAGE_SAMPLES; i++) {
    sum += analogRead(pin);
    delayMicroseconds(10);
  }
  return sum / KEY_ADC_AVERAGE_SAMPLES;
}

/*
  Physical mapping confirmed from PCB/user notes:

  - S1-S8   / AM0:0-7          => aux keys, LEDs 1-8
  - S9-S18  / AM0:8-15+AM1:0-1 => black keys, LEDs 9-18
  - S19-S32 / AM1:2-15         => white keys, LEDs 19-32

  keyDefs[] keeps musical keys first for keyToNote[], then aux keys.
  Use physicalLedIndexForKeyIndex() whenever touching the LED strip.
*/
void initKeyDefs() {
  // Aux switches S1-S8: logical indices 24-31 on AM0:0-7
  for (uint8_t i = 0; i < NUM_EXTRA_KEYS; i++) {
    uint8_t keyIndex = NUM_MAIN_KEYS + i; // logical aux 24-31
    keyDefs[keyIndex].muxIndex   = 0;     // AM0
    keyDefs[keyIndex].muxChannel = i;     // physical S1-S8
    keyDefs[keyIndex].isExtra    = true;
  }

  // Black switches S9-S16: main key indices 0-7 on AM0:8-15
  for (uint8_t i = 0; i < 8; i++) {
    keyDefs[i].muxIndex   = 0;        // AM0
    keyDefs[i].muxChannel = 8 + i;    // physical S9-S16
    keyDefs[i].isExtra    = false;
  }

  // Black switches S17-S18, then white switches S19-S32: main indices 8-23 on AM1:0-15
  for (uint8_t i = 0; i < 16; i++) {
    uint8_t keyIndex = 8 + i;        // logical main 8-23
    keyDefs[keyIndex].muxIndex   = 1; // AM1
    keyDefs[keyIndex].muxChannel = i; // physical S17-S32
    keyDefs[keyIndex].isExtra    = false;
  }
}

void calibrateKeys() {
  const uint8_t samples = 32;
  for (uint8_t k = 0; k < TOTAL_KEYS; k++) {
    uint32_t sum = 0;
    for (uint8_t s = 0; s < samples; s++) {
      sum += readKeyRaw(keyDefs[k]);
      delay(1);
    }
    keyStates[k].baseline = (uint16_t)(sum / samples);
    keyStates[k].raw = keyStates[k].baseline;
    keyStates[k].pressed = false;
    keyStates[k].velocityComputed = false;
    keyStates[k].extraHandled = false;
    keyStates[k].extraSuppressed = false;
    keyStates[k].activeNote = 0;
    keyStates[k].aboveCount = 0;
    keyStates[k].belowCount = 0;
  }
}

uint8_t computeVelocity(uint16_t delta, uint32_t dtUs) {
  (void)delta;
  if (dtUs <= VELOCITY_MIN_DT_US) return 127;
  if (dtUs >= VELOCITY_MAX_DT_US) return 10;

  float t = (float)(dtUs - VELOCITY_MIN_DT_US) /
            (float)(VELOCITY_MAX_DT_US - VELOCITY_MIN_DT_US);
  t = constrain(1.0f - t, 0.0f, 1.0f);
  uint8_t vel = (uint8_t)(10 + t * (127 - 10));
  if (vel < 1) vel = 1;
  return vel;
}

void setKeyLedBase(uint8_t keyIndex, uint8_t velocity, bool on);
void startRipple(uint8_t note, uint8_t velocity);

bool anyMainKeyActive() {
  for (uint8_t i = 0; i < NUM_MAIN_KEYS; i++) {
    if (keyStates[i].velocityComputed) return true;
  }
  return false;
}

bool settingsChangesAllowed() {
  return !anyMainKeyActive() && (millis() - lastMainKeyActivityMs) >= SETTINGS_AFTER_KEYS_COOLDOWN_MS;
}

bool songModeImmediateExtraKey(uint8_t keyIndex) {
  if (!FractureSongs::isActive() || keyIndex < NUM_MAIN_KEYS) return false;
  uint8_t extraIndex = keyIndex - NUM_MAIN_KEYS;
  return extraIndex == 0 || extraIndex >= 6;
}

uint32_t extraKeyHoldUs(uint8_t keyIndex) {
  (void)keyIndex;
  return FractureSongs::isActive() ? (AUX_HOLD_US / 2) : AUX_HOLD_US;
}

bool extraKeyActionAllowed(uint8_t keyIndex) {
  if (FractureSongs::isActive()) return true;
  if (songModeImmediateExtraKey(keyIndex)) return true;
  return settingsChangesAllowed();
}
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
void loop() {
  if (remapScheduled && (int32_t)(millis() - remapStartAtMs) >= 0) {
    remapScheduled = false;
    startDiscovery(true);
  }

  processRs485();

  scanKeys();
  handleEncoderButton();
  handleEncoderMovement();
  FractureSongs::update();

  audioGenerateAndWrite();

  uint32_t nowMs = millis();
  if (FractureSongs::blocksNetworkMaintenance()) {
    awaitingPingReplies = false;
  } else if (myBoardIndex == 0 && totalBoards > 1) {
    if (!awaitingPingReplies && (nowMs - lastPingMs > PING_INTERVAL_MS)) {
      sendPing();
      lastPingMs = nowMs;
    } else if (awaitingPingReplies && (nowMs - pingStartMs > PING_TIMEOUT_MS)) {
      bool missing = false;
      for (uint8_t i = 0; i < nodeList.count; i++) {
        if (!pingReceived[i]) {
          missing = true;
          break;
        }
      }
      awaitingPingReplies = false;
      if (missing) {
        networkHealthy = false;
        requestNetworkRemap();
      } else {
        networkHealthy = true;
      }
    }
  }

  renderLeds();

  delay(2);
}

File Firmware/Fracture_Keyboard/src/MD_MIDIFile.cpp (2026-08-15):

/*
  MD_MIDIFile.cpp - An Arduino library for processing Standard MIDI Files (SMF).
  Copyright (C) 2012 Marco Colli
  All rights reserved.

  See MD_MIDIFile.h for complete comments

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
  You should have received a copy of the GNU Lesser General Public
  License along with this library; if not, write to the Free Software
  Foundation, Inc., 51 Franklin St, Fifth Floor, Boston, MA  02110-1301  USA
*/

#include <string.h>
#include "MD_MIDIFile.h"
#include "MD_MIDIHelper.h"

/**
 * \file
 * \brief Main file for the MD_MIDIFile class implementation
 */

void MD_MIDIFile::initialise(void)
{
  _trackCount = 0;            // number of tracks in file
  _format = 0;
  _tickTime = _lastTickError = 0;
  _synchDone = false;
  _paused =_looping = false;
  
  setMidiHandler(nullptr);
  setSysexHandler(nullptr);
  setMetaHandler(nullptr);

  // File handling
  setFilename("");
  _sd = nullptr;

  // Set MIDI specified standard defaults
  setTicksPerQuarterNote(48); // 48 ticks per quarter note
  setTempo(120);              // 120 beats per minute
  setTempoAdjust(0);          // 0 beats per minute adjustment
  setMicrosecondPerQuarterNote(500000);  // 500,000 microseconds per quarter note
  setTimeSignature(4, 4);     // 4/4 time
}

void MD_MIDIFile::synchTracks(void)
{
  for (uint8_t i = 0; i < _trackCount; i++)
    _track[i].syncTime();

  _lastTickCheckTime = micros();
  _lastTickError = 0;
}

MD_MIDIFile::MD_MIDIFile(void) 
{ 
  initialise();
}

MD_MIDIFile::~MD_MIDIFile() 
{ 
  close();
}

void MD_MIDIFile::begin(SDFAT *psd)
{
  _sd = psd;
}

void MD_MIDIFile::close()
// Close out - should be ready for the next file
{
  for (uint8_t i = 0; i<_trackCount; i++)
  {
    _track[i].close();
  }
  _trackCount = 0;
  _synchDone = false;
  _paused = false;

  setFilename("");
  _fd.close();
}

void MD_MIDIFile::setTempoAdjust(int16_t t)
{
  if ((t + _tempo) > 0) _tempoDelta = t;
  calcTickTime();
}

void MD_MIDIFile::setTempo(uint16_t t)
{
  if ((_tempoDelta + t) > 0) _tempo = t;
  calcTickTime();
}

void MD_MIDIFile::setTimeSignature(uint8_t n, uint8_t d)
{
  _timeSignature[0] = n;
  _timeSignature[1] = d;
  calcTickTime();
}

void MD_MIDIFile::setTicksPerQuarterNote(uint16_t ticks) 
{
  _ticksPerQuarterNote = ticks;
  calcTickTime();
}

void MD_MIDIFile::setMicrosecondPerQuarterNote(uint32_t m)
// This is the value given in the META message setting tempo
{
  // work out the tempo from the delta by reversing the calcs in
  // calctickTime - m is already per quarter note
  _tempo = (60 * 1000000L) / m;
  calcTickTime();
}

void MD_MIDIFile::calcTickTime(void) 
// 1 tick = microseconds per beat / ticks per Q note
// The variable "microseconds per beat" is specified by a MIDI event carrying 
// the set tempo meta message. If it is not specified then it is 500,000 microseconds 
// by default, which is equivalent to 120 beats per minute. 
// If the MIDI time division is 60 ticks per beat and if the microseconds per beat 
// is 500,000, then 1 tick = 500,000 / 60 = 8333.33 microseconds.
{
  if ((_tempo + _tempoDelta != 0) && _ticksPerQuarterNote != 0 && _timeSignature[1] != 0)
  {
    _tickTime = (60 * 1000000L) / (_tempo + _tempoDelta); // microseconds per beat
//    _tickTime = (_tickTime * 4) / (_timeSignature[1] * _ticksPerQuarterNote); // microseconds per tick
    _tickTime /= _ticksPerQuarterNote;
  }
}

bool MD_MIDIFile::isEOF(void)
{
  bool bEof = true;

  // check if each track has finished
  for (uint8_t i=0; i<_trackCount && bEof; i++)
  {
    bEof = (_track[i].getEndOfTrack() && bEof);  // breaks at first false
  }
  
  if (bEof) DUMPS("\n! EOF");

  // if looping and all tracks done, reset to the start
  if (bEof && _looping)
  {
    restart();
    bEof = false;
  }

  return(bEof);
}

void MD_MIDIFile::pause(bool bMode)
// Start pause when true and restart when false
{
  _paused = bMode;

  if (!_paused)         // restarting so adjust the time last checked to now
    _lastTickCheckTime = micros();
}

void MD_MIDIFile::restart(void)
// Reset the file to the start of all tracks
{
  // track 0 contains information that does not need to be reloaded every time, 
  // so if we are looping, ignore restarting that track. The file may have one 
  // track only and in this case always sync from track 0.
  for (uint8_t i=(_looping && _trackCount>1 ? 1 : 0); i<_trackCount; i++)
    _track[i].restart();

  _synchDone = false;   // force a time resych as well
}

uint16_t MD_MIDIFile::tickClock(void)
// check if enough time has passed for a MIDI tick and work out how many!
{
  uint32_t  elapsedTime;
  uint16_t  ticks = 0;

  elapsedTime = _lastTickError + micros() - _lastTickCheckTime;
  if (elapsedTime >= _tickTime)
  {
    ticks = elapsedTime/_tickTime;
    _lastTickError = elapsedTime - (_tickTime * ticks);
    _lastTickCheckTime = micros();    // save for next round of checks
  }

  return(ticks);
}

boolean MD_MIDIFile::getNextEvent(void)
{
  uint16_t  ticks;

  // if we are paused we are paused!
  if (_paused) 
    return false;

  // sync start all the tracks if we need to
  if (!_synchDone)
  {
    synchTracks();
    _synchDone = true;
  }

  // check if enough time has passed for a MIDI tick
  if ((ticks = tickClock()) == 0)
    return false;

  processEvents(ticks);

  return(true);
}

void MD_MIDIFile::processEvents(uint16_t ticks)
{
  uint8_t n;

  if (_format != 0) 
  {
    DUMP("\n-- [", ticks); 
    DUMPS("] TRK "); 
  }

#if TRACK_PRIORITY
  // process all events from each track first - TRACK PRIORITY
  for (uint8_t i = 0; i < _trackCount; i++)
  {
    if (_format != 0) DUMPX("", i);
    // Limit n to be a sensible number of events in the loop counter
    // When there are no more events, just break out
    // Other than the first event, the others have an elapsed time of 0 (ie occur simultaneously)
    for (n=0; n < 100; n++)
    {
      if (!_track[i].getNextEvent(this, (n==0 ? ticks : 0)))
        break;
    }

    if ((n > 0) && (_format != 0))
      DUMPS("\n-- TRK "); 
  }
#else // EVENT_PRIORITY
  // process one event from each track round-robin style - EVENT PRIORITY
  bool doneEvents;

  // Limit n to be a sensible number of events in the loop counter
  for (n = 0; (n < 100) && (!doneEvents); n++)
  {
    doneEvents = false;

    for (uint8_t i = 0; i < _trackCount; i++) // cycle through all
    {
      bool b;

      if (_format != 0) DUMPX("", i);

      // Other than the first event, the other have an elapsed time of 0 (ie occur simultaneously)
      b = _track[i].getNextEvent(this, (n==0 ? ticks : 0));
      if (b && (_format != 0))
        DUMPS("\n-- TRK "); 
      doneEvents = (doneEvents || b);
    }

    // When there are no more events, just break out
    if (!doneEvents)
      break;
  } 
#endif // EVENT/TRACK_PRIORITY
}
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

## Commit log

2025-12-17 Empty repos are scary
    Added the parts I will use
    [Fracture.kicad_pcb, Fracture.kicad_sch]
2025-12-17 Schematic essentials
    [Fracture.kicad_sch]
2025-12-18 Impedance matching and 4 layers
    The PCB is now a 4 layer board for better ground pour coverage and to allow for proper impedance matching as needed by ethernet.
    PCB Toolkit was used to calculate the new widths needed for proper ethernet trace impedance.
2025-12-20 Schematic Done + PCB Layout Done
    [Analog Input.kicad_sch, Audio Output.kicad_sch, Fracture.kicad_pcb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]
2025-12-20 PCB routing done
    [Audio Output.kicad_sch, Fracture.kicad_sch]
2025-12-20 PCB Done and Panelized!
    [Audio Output.kicad_sch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]
2025-12-31 Renders and Gerbers
    [Fracture-B_Cu.gbr, Fracture-B_Mask.gbr, Fracture-B_Paste.gbr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]
2025-12-31 Update neighbor wiring pin definitions
2025-12-31 Added sensing pins and Schematic Renders
    [Fracture-B_Cu.gbr, Fracture-B_Mask.gbr, Fracture-B_Paste.gbr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]
2026-01-01 BOM + PCB Order Prep
    The cost is significantly cheaper to put the PCBs as 2 separate orders rather than paying the panelization fee.
    [BOM.csv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]
2026-01-02 BOM Update
    [BOM.csv]
